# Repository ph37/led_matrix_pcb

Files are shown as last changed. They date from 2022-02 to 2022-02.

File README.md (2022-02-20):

# 32x16 LED Array PCB using 788BS

KiKad 5.1 files for the design of an LED matrix. The board has been manufactured by PCB Way and is
working.

The design is based around 788BS LED modules, which each contain 8x8 red LEDs in a common cathode
configuration.

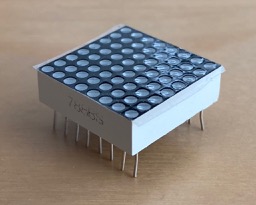
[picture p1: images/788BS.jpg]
Photo of 788BS


While physically a 16 row and 32 column design, it is logically organised as 8 rows and 64
columns. Logical row N drives physical rows N and N+8.

Uses a 3-pin header to drive a series of 74HC595 shift registers. First shift register is connected to a 
74HC238 3-to-8 decoder to provide hardware enforced one-hot enable of rows. Rows are driven by a PMV16XN 
SMT power MOSFET to provide enough current to drive 32 LED columns.

Another eight 8-bit shift registers provide control over the 64 columns, with each column
using a 680 ohm resistor to limit current. Brightness of individual LEDs can be supported
externally by reprogramming the shift register and pulse-width-modulating the on-time for
each column.

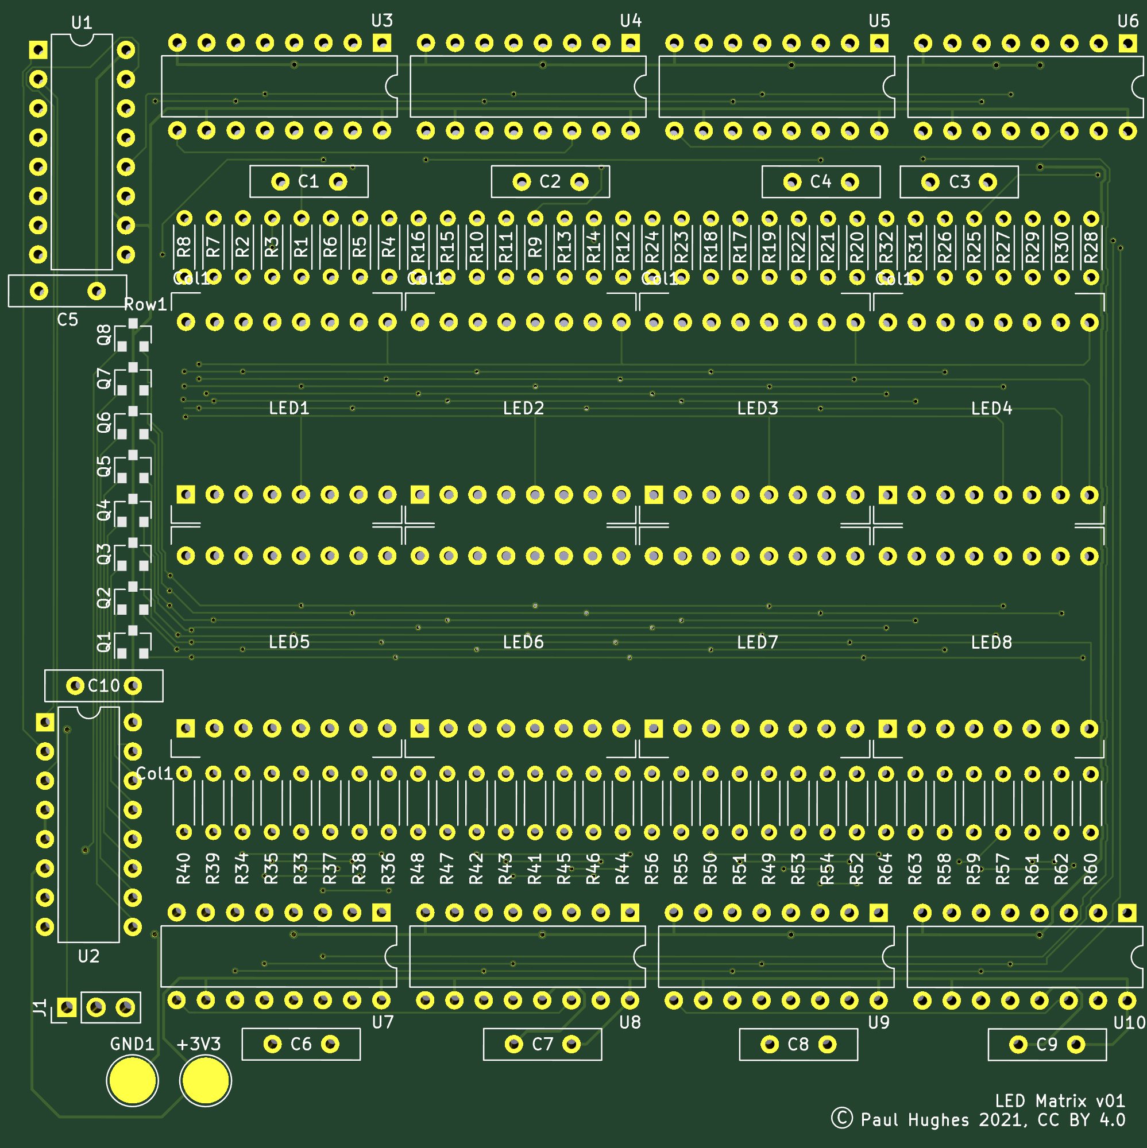
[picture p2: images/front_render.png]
Render of PCB


## Notes

Board layout is intended for manufacture by PCB Way and follows PCB Way design rules. Please check
compatibility with design rules for any other PCB house.

Board is a very basic design and intended for low frequency operation only. In particular there is
no ground plane, which I plan to include in a future revision.

Take care with 788BS parts, I recommend testing them before soldering onto the board. 
The first board I've built has a short circuit inside one of 788BS components, are these 
are difficult to remove as the pins are underneath the package.

## Errata

v01 of the board transposed rows 6 and 7 on the included 788BS symbol. This can be resolved
by transposing the data for these rows in software before driving the serial interface.

## Future

I plan to release C drivers for Paspberry Pi Pico. Eventually I plan to migrate the IO the Pico's
programmable IO.

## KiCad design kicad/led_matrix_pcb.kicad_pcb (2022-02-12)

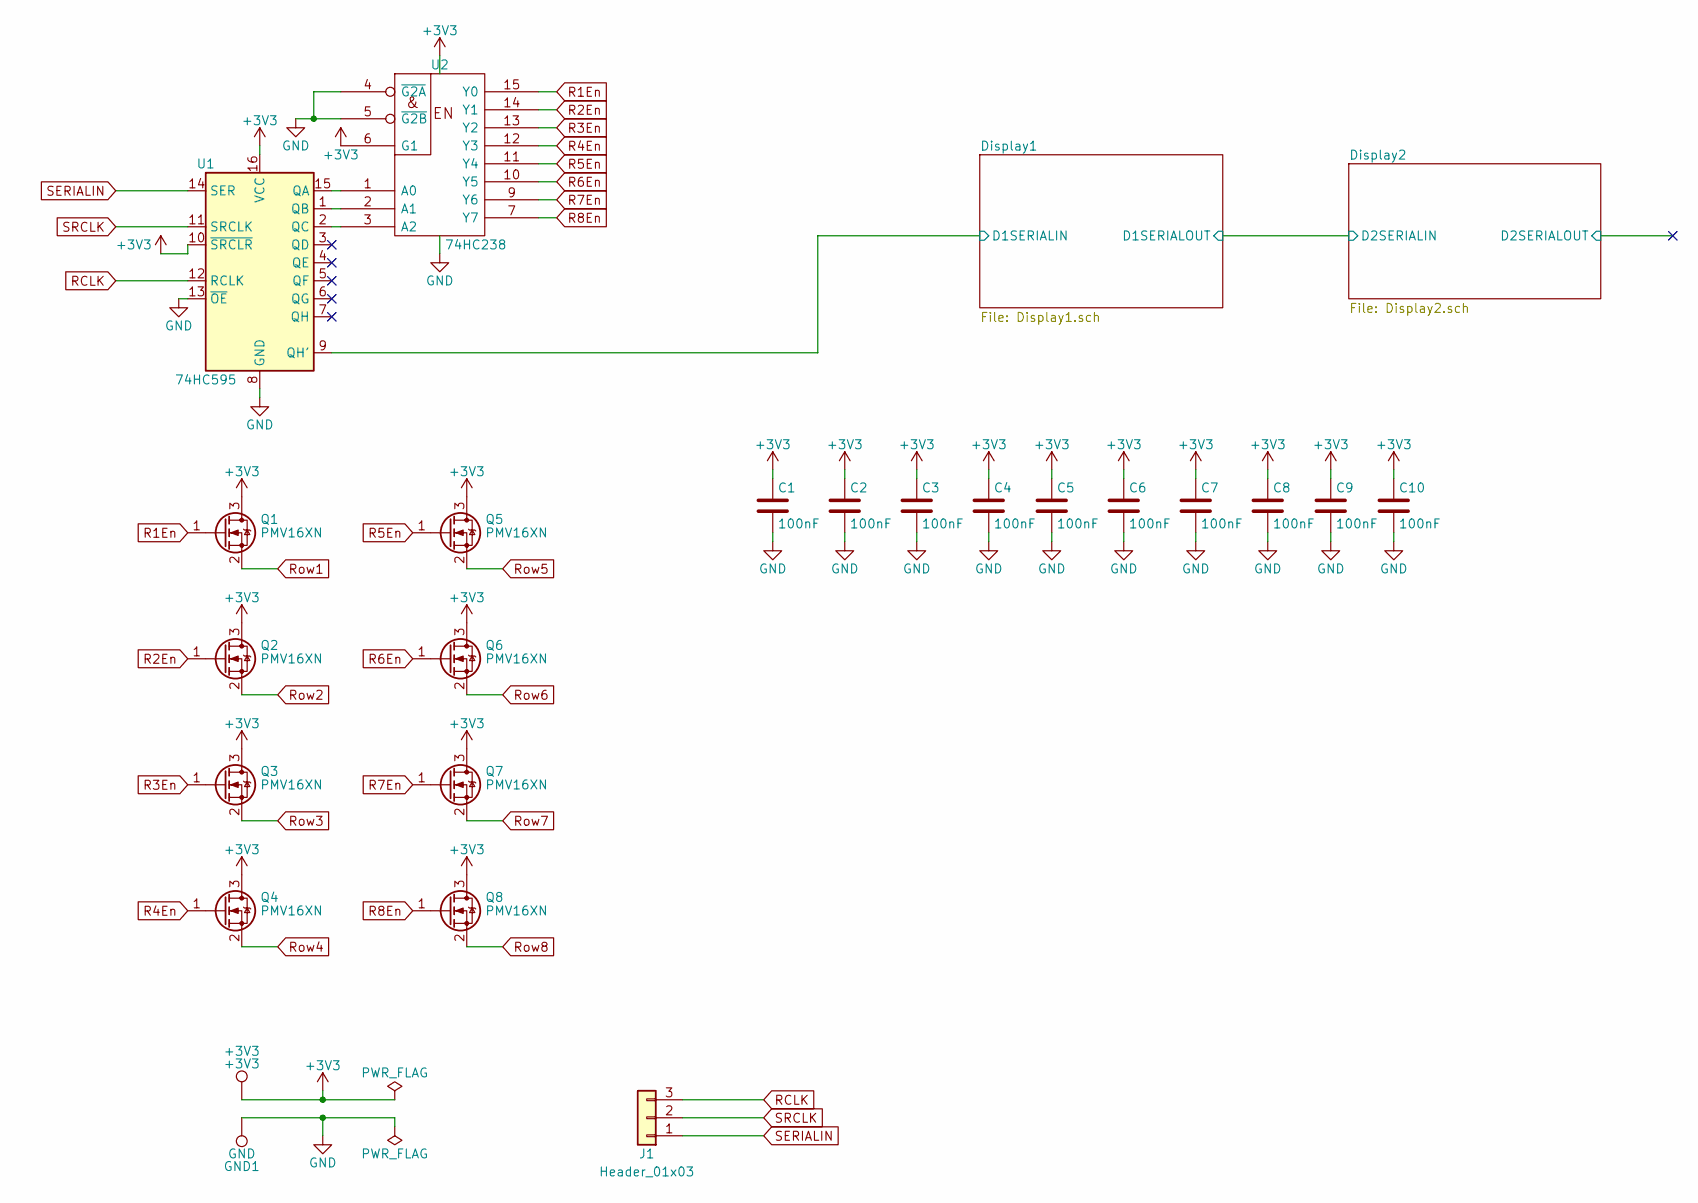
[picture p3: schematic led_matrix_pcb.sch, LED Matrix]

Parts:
+3V3: +3V3; TestPoint_Pad_D4.0mm
C1, C2, C3, C4, C5, C6, C7, C8, C9, C10: 100nF; C_Disc_D10.0mm_W2.5mm_P5.00mm
GND1: GND; TestPoint_Pad_D4.0mm
J1: Header_01x03; PinHeader_1x03_P2.54mm_Vertical
Q1, Q2, Q3, Q4, Q5, Q6, Q7, Q8: PMV16XN; SOT-23
U1: 74HC595; DIP-16_W7.62mm
U2: 74HC238; DIP-16_W7.62mm

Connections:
+3V3: +3V3.1, C1.1, C2.1, C3.1, C4.1, C5.1, C6.1, C7.1, C8.1, C9.1, C10.1, Q1.3 (D), Q2.3 (D), Q3.3 (D), Q4.3 (D), Q5.3 (D), Q6.3 (D), Q7.3 (D), Q8.3 (D), U1.10 (~SRCLR), U1.16 (VCC), U2.6 (G1), U2.16 (VCC); also elsewhere on the board
/Display1/D1SERIALIN: U1.9 (QH'); also elsewhere on the board
GND: C1.2, C2.2, C3.2, C4.2, C5.2, C6.2, C7.2, C8.2, C9.2, C10.2, GND1.1, U1.8 (GND), U1.13 (~OE), U2.4 (~G2A), U2.5 (~G2B), U2.8 (GND); also elsewhere on the board
unnamed: U1.1 (QB), U2.2 (A1)
unnamed: U1.2 (QC), U2.3 (A2)
unnamed: U1.15 (QA), U2.1 (A0)
R1En: Q1.1 (G), U2.15 (Y0)
R2En: Q2.1 (G), U2.14 (Y1)
R3En: Q3.1 (G), U2.13 (Y2)
R4En: Q4.1 (G), U2.12 (Y3)
R5En: Q5.1 (G), U2.11 (Y4)
R6En: Q6.1 (G), U2.10 (Y5)
R7En: Q7.1 (G), U2.9 (Y6)
R8En: Q8.1 (G), U2.7 (Y7)
RCLK: J1.3, U1.12 (RCLK); also elsewhere on the board
Row1: Q1.2 (S); also elsewhere on the board
Row2: Q2.2 (S); also elsewhere on the board
Row3: Q3.2 (S); also elsewhere on the board
Row4: Q4.2 (S); also elsewhere on the board
Row5: Q5.2 (S); also elsewhere on the board
Row6: Q6.2 (S); also elsewhere on the board
Row7: Q7.2 (S); also elsewhere on the board
Row8: Q8.2 (S); also elsewhere on the board
SERIALIN: J1.1, U1.14 (SER)
SRCLK: J1.2, U1.11 (SRCLK); also elsewhere on the board

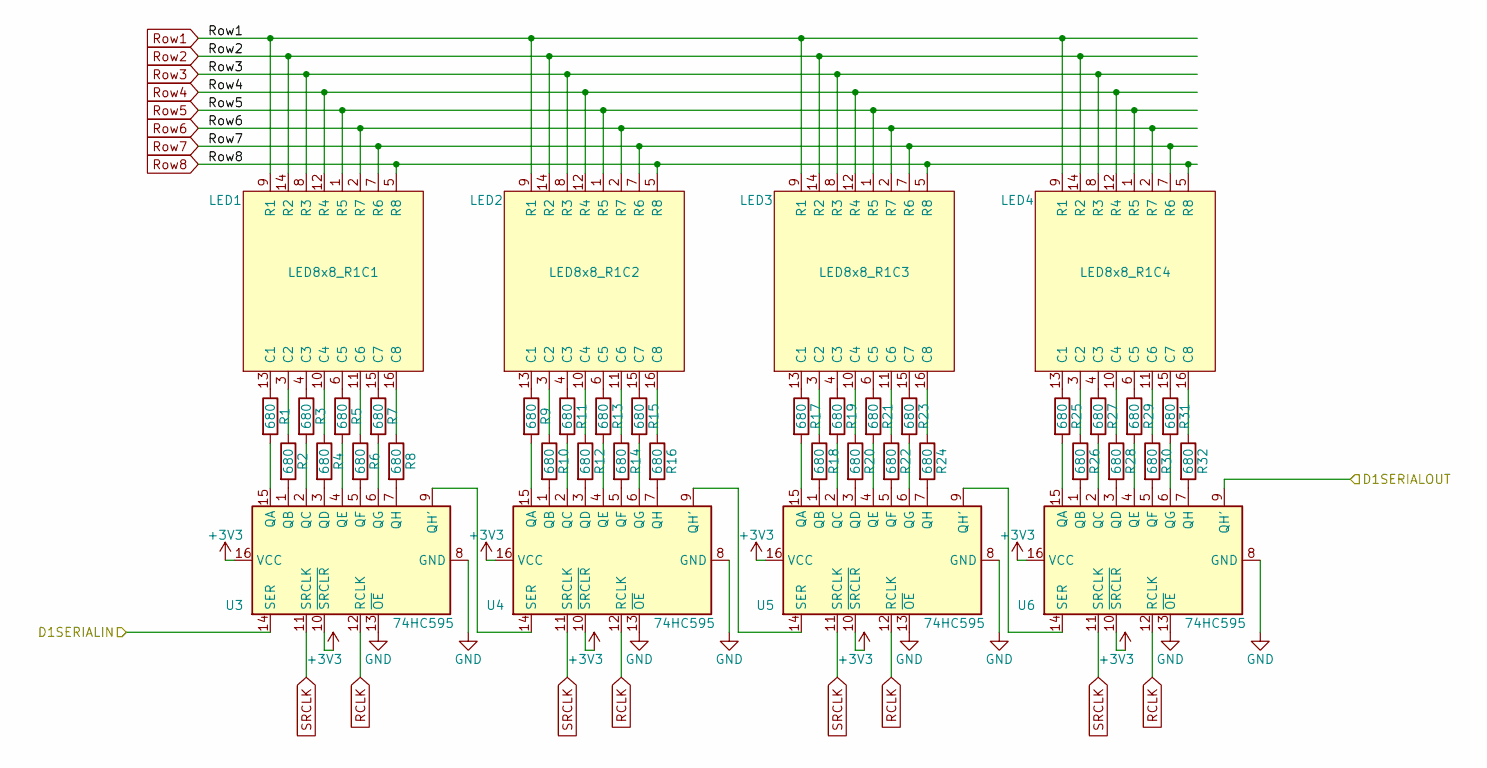
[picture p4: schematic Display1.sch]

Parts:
LED1: LED8x8_R1C1; 788BS
LED2: LED8x8_R1C2; 788BS
LED3: LED8x8_R1C3; 788BS
LED4: LED8x8_R1C4; 788BS
R1, R2, R3, R4, R5, R6, R7, R8, R9, R10, R11, R12, R13, R14, R15, R16, R17, R18, R19, R20, R21, R22, R23, R24, R25, R26, R27, R28, R29, R30, R31, R32: 680; R_Axial_DIN0204_L3.6mm_D1.6mm_P5.08mm_Horizontal
U3, U4, U5, U6: 74HC595; DIP-16_W7.62mm

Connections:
+3V3: U3.10 (~SRCLR), U3.16 (VCC), U4.10 (~SRCLR), U4.16 (VCC), U5.10 (~SRCLR), U5.16 (VCC), U6.10 (~SRCLR), U6.16 (VCC); also elsewhere on the board
/Display1/D1SERIALIN: U3.14 (SER); also elsewhere on the board
/Display1/D1SERIALOUT: U6.9 (QH'); also elsewhere on the board
GND: U3.8 (GND), U3.13 (~OE), U4.8 (GND), U4.13 (~OE), U5.8 (GND), U5.13 (~OE), U6.8 (GND), U6.13 (~OE); also elsewhere on the board
unnamed: LED1.3 (C2), R2.1
unnamed: LED1.4 (C3), R3.1
unnamed: LED1.6 (C5), R5.1
unnamed: LED1.10 (C4), R4.1
unnamed: LED1.11 (C6), R6.1
unnamed: LED1.13 (C1), R1.1
unnamed: LED1.15 (C7), R7.1
unnamed: LED1.16 (C8), R8.1
unnamed: LED2.3 (C2), R10.1
unnamed: LED2.4 (C3), R11.1
unnamed: LED2.6 (C5), R13.1
unnamed: LED2.10 (C4), R12.1
unnamed: LED2.11 (C6), R14.1
unnamed: LED2.13 (C1), R9.1
unnamed: LED2.15 (C7), R15.1
unnamed: LED2.16 (C8), R16.1
unnamed: LED3.3 (C2), R18.1
unnamed: LED3.4 (C3), R19.1
unnamed: LED3.6 (C5), R21.1
unnamed: LED3.10 (C4), R20.1
unnamed: LED3.11 (C6), R22.1
unnamed: LED3.13 (C1), R17.1
unnamed: LED3.15 (C7), R23.1
unnamed: LED3.16 (C8), R24.1
unnamed: LED4.3 (C2), R26.1
unnamed: LED4.4 (C3), R27.1
unnamed: LED4.6 (C5), R29.1
unnamed: LED4.10 (C4), R28.1
unnamed: LED4.11 (C6), R30.1
unnamed: LED4.13 (C1), R25.1
unnamed: LED4.15 (C7), R31.1
unnamed: LED4.16 (C8), R32.1
unnamed: R1.2, U3.15 (QA)
unnamed: R2.2, U3.1 (QB)
unnamed: R3.2, U3.2 (QC)
unnamed: R4.2, U3.3 (QD)
unnamed: R5.2, U3.4 (QE)
unnamed: R6.2, U3.5 (QF)
unnamed: R7.2, U3.6 (QG)
unnamed: R8.2, U3.7 (QH)
unnamed: R9.2, U4.15 (QA)
unnamed: R10.2, U4.1 (QB)
unnamed: R11.2, U4.2 (QC)
unnamed: R12.2, U4.3 (QD)
unnamed: R13.2, U4.4 (QE)
unnamed: R14.2, U4.5 (QF)
unnamed: R15.2, U4.6 (QG)
unnamed: R16.2, U4.7 (QH)
unnamed: R17.2, U5.15 (QA)
unnamed: R18.2, U5.1 (QB)
unnamed: R19.2, U5.2 (QC)
unnamed: R20.2, U5.3 (QD)
unnamed: R21.2, U5.4 (QE)
unnamed: R22.2, U5.5 (QF)
unnamed: R23.2, U5.6 (QG)
unnamed: R24.2, U5.7 (QH)
unnamed: R25.2, U6.15 (QA)
unnamed: R26.2, U6.1 (QB)
unnamed: R27.2, U6.2 (QC)
unnamed: R28.2, U6.3 (QD)
unnamed: R29.2, U6.4 (QE)
unnamed: R30.2, U6.5 (QF)
unnamed: R31.2, U6.6 (QG)
unnamed: R32.2, U6.7 (QH)
unnamed: U3.9 (QH'), U4.14 (SER)
unnamed: U4.9 (QH'), U5.14 (SER)
unnamed: U5.9 (QH'), U6.14 (SER)
RCLK: U3.12 (RCLK), U4.12 (RCLK), U5.12 (RCLK), U6.12 (RCLK); also elsewhere on the board
Row1: LED1.9 (R1), LED2.9 (R1), LED3.9 (R1), LED4.9 (R1); also elsewhere on the board
Row2: LED1.14 (R2), LED2.14 (R2), LED3.14 (R2), LED4.14 (R2); also elsewhere on the board
Row3: LED1.8 (R3), LED2.8 (R3), LED3.8 (R3), LED4.8 (R3); also elsewhere on the board
Row4: LED1.12 (R4), LED2.12 (R4), LED3.12 (R4), LED4.12 (R4); also elsewhere on the board
Row5: LED1.1 (R5), LED2.1 (R5), LED3.1 (R5), LED4.1 (R5); also elsewhere on the board
Row6: LED1.2 (R7), LED2.2 (R7), LED3.2 (R7), LED4.2 (R7); also elsewhere on the board
Row7: LED1.7 (R6), LED2.7 (R6), LED3.7 (R6), LED4.7 (R6); also elsewhere on the board
Row8: LED1.5 (R8), LED2.5 (R8), LED3.5 (R8), LED4.5 (R8); also elsewhere on the board
SRCLK: U3.11 (SRCLK), U4.11 (SRCLK), U5.11 (SRCLK), U6.11 (SRCLK); also elsewhere on the board

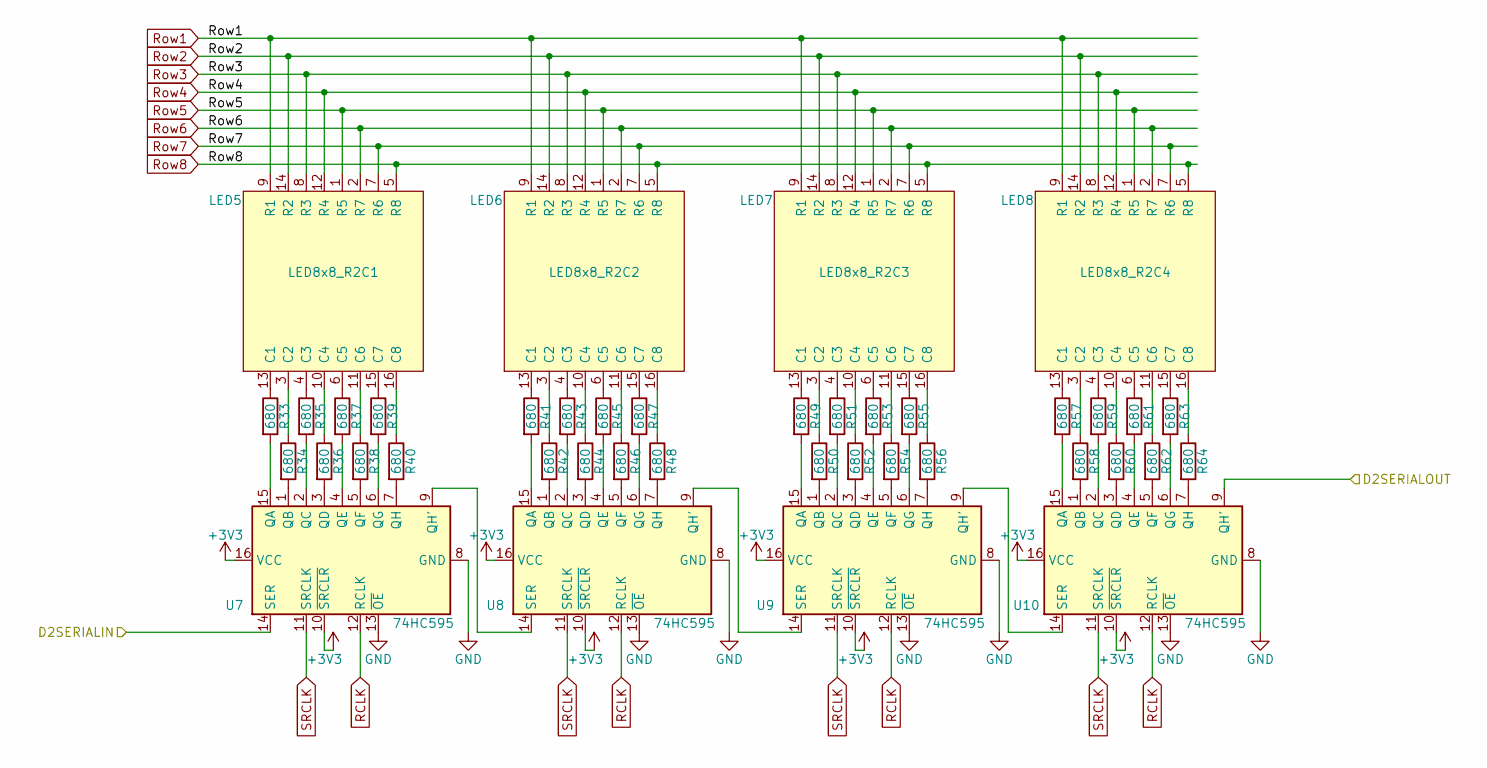
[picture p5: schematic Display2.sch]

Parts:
LED5: LED8x8_R2C1; 788BS
LED6: LED8x8_R2C2; 788BS
LED7: LED8x8_R2C3; 788BS
LED8: LED8x8_R2C4; 788BS
R33, R34, R35, R36, R37, R38, R39, R40, R41, R42, R43, R44, R45, R46, R47, R48, R49, R50, R51, R52, R53, R54, R55, R56, R57, R58, R59, R60, R61, R62, R63, R64: 680; R_Axial_DIN0204_L3.6mm_D1.6mm_P5.08mm_Horizontal
U7, U8, U9, U10: 74HC595; DIP-16_W7.62mm

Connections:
+3V3: U7.10 (~SRCLR), U7.16 (VCC), U8.10 (~SRCLR), U8.16 (VCC), U9.10 (~SRCLR), U9.16 (VCC), U10.10 (~SRCLR), U10.16 (VCC); also elsewhere on the board
/Display1/D1SERIALOUT: U7.14 (SER); also elsewhere on the board
/Display2/D2SERIALOUT: U10.9 (QH')
GND: U7.8 (GND), U7.13 (~OE), U8.8 (GND), U8.13 (~OE), U9.8 (GND), U9.13 (~OE), U10.8 (GND), U10.13 (~OE); also elsewhere on the board
unnamed: LED5.3 (C2), R34.1
unnamed: LED5.4 (C3), R35.1
unnamed: LED5.6 (C5), R37.1
unnamed: LED5.10 (C4), R36.1
unnamed: LED5.11 (C6), R38.1
unnamed: LED5.13 (C1), R33.1
unnamed: LED5.15 (C7), R39.1
unnamed: LED5.16 (C8), R40.1
unnamed: LED6.3 (C2), R42.1
unnamed: LED6.4 (C3), R43.1
unnamed: LED6.6 (C5), R45.1
unnamed: LED6.10 (C4), R44.1
unnamed: LED6.11 (C6), R46.1
unnamed: LED6.13 (C1), R41.1
unnamed: LED6.15 (C7), R47.1
unnamed: LED6.16 (C8), R48.1
unnamed: LED7.3 (C2), R50.1
unnamed: LED7.4 (C3), R51.1
unnamed: LED7.6 (C5), R53.1
unnamed: LED7.10 (C4), R52.1
unnamed: LED7.11 (C6), R54.1
unnamed: LED7.13 (C1), R49.1
unnamed: LED7.15 (C7), R55.1
unnamed: LED7.16 (C8), R56.1
unnamed: LED8.3 (C2), R58.1
unnamed: LED8.4 (C3), R59.1
unnamed: LED8.6 (C5), R61.1
unnamed: LED8.10 (C4), R60.1
unnamed: LED8.11 (C6), R62.1
unnamed: LED8.13 (C1), R57.1
unnamed: LED8.15 (C7), R63.1
unnamed: LED8.16 (C8), R64.1
unnamed: R33.2, U7.15 (QA)
unnamed: R34.2, U7.1 (QB)
unnamed: R35.2, U7.2 (QC)
unnamed: R36.2, U7.3 (QD)
unnamed: R37.2, U7.4 (QE)
unnamed: R38.2, U7.5 (QF)
unnamed: R39.2, U7.6 (QG)
unnamed: R40.2, U7.7 (QH)
unnamed: R41.2, U8.15 (QA)
unnamed: R42.2, U8.1 (QB)
unnamed: R43.2, U8.2 (QC)
unnamed: R44.2, U8.3 (QD)
unnamed: R45.2, U8.4 (QE)
unnamed: R46.2, U8.5 (QF)
unnamed: R47.2, U8.6 (QG)
unnamed: R48.2, U8.7 (QH)
unnamed: R49.2, U9.15 (QA)
unnamed: R50.2, U9.1 (QB)
unnamed: R51.2, U9.2 (QC)
unnamed: R52.2, U9.3 (QD)
unnamed: R53.2, U9.4 (QE)
unnamed: R54.2, U9.5 (QF)
unnamed: R55.2, U9.6 (QG)
unnamed: R56.2, U9.7 (QH)
unnamed: R57.2, U10.15 (QA)
unnamed: R58.2, U10.1 (QB)
unnamed: R59.2, U10.2 (QC)
unnamed: R60.2, U10.3 (QD)
unnamed: R61.2, U10.4 (QE)
unnamed: R62.2, U10.5 (QF)
unnamed: R63.2, U10.6 (QG)
unnamed: R64.2, U10.7 (QH)
unnamed: U7.9 (QH'), U8.14 (SER)
unnamed: U8.9 (QH'), U9.14 (SER)
unnamed: U9.9 (QH'), U10.14 (SER)
RCLK: U7.12 (RCLK), U8.12 (RCLK), U9.12 (RCLK), U10.12 (RCLK); also elsewhere on the board
Row1: LED5.9 (R1), LED6.9 (R1), LED7.9 (R1), LED8.9 (R1); also elsewhere on the board
Row2: LED5.14 (R2), LED6.14 (R2), LED7.14 (R2), LED8.14 (R2); also elsewhere on the board
Row3: LED5.8 (R3), LED6.8 (R3), LED7.8 (R3), LED8.8 (R3); also elsewhere on the board
Row4: LED5.12 (R4), LED6.12 (R4), LED7.12 (R4), LED8.12 (R4); also elsewhere on the board
Row5: LED5.1 (R5), LED6.1 (R5), LED7.1 (R5), LED8.1 (R5); also elsewhere on the board
Row6: LED5.2 (R7), LED6.2 (R7), LED7.2 (R7), LED8.2 (R7); also elsewhere on the board
Row7: LED5.7 (R6), LED6.7 (R6), LED7.7 (R6), LED8.7 (R6); also elsewhere on the board
Row8: LED5.5 (R8), LED6.5 (R8), LED7.5 (R8), LED8.5 (R8); also elsewhere on the board
SRCLK: U7.11 (SRCLK), U8.11 (SRCLK), U9.11 (SRCLK), U10.11 (SRCLK); also elsewhere on the board

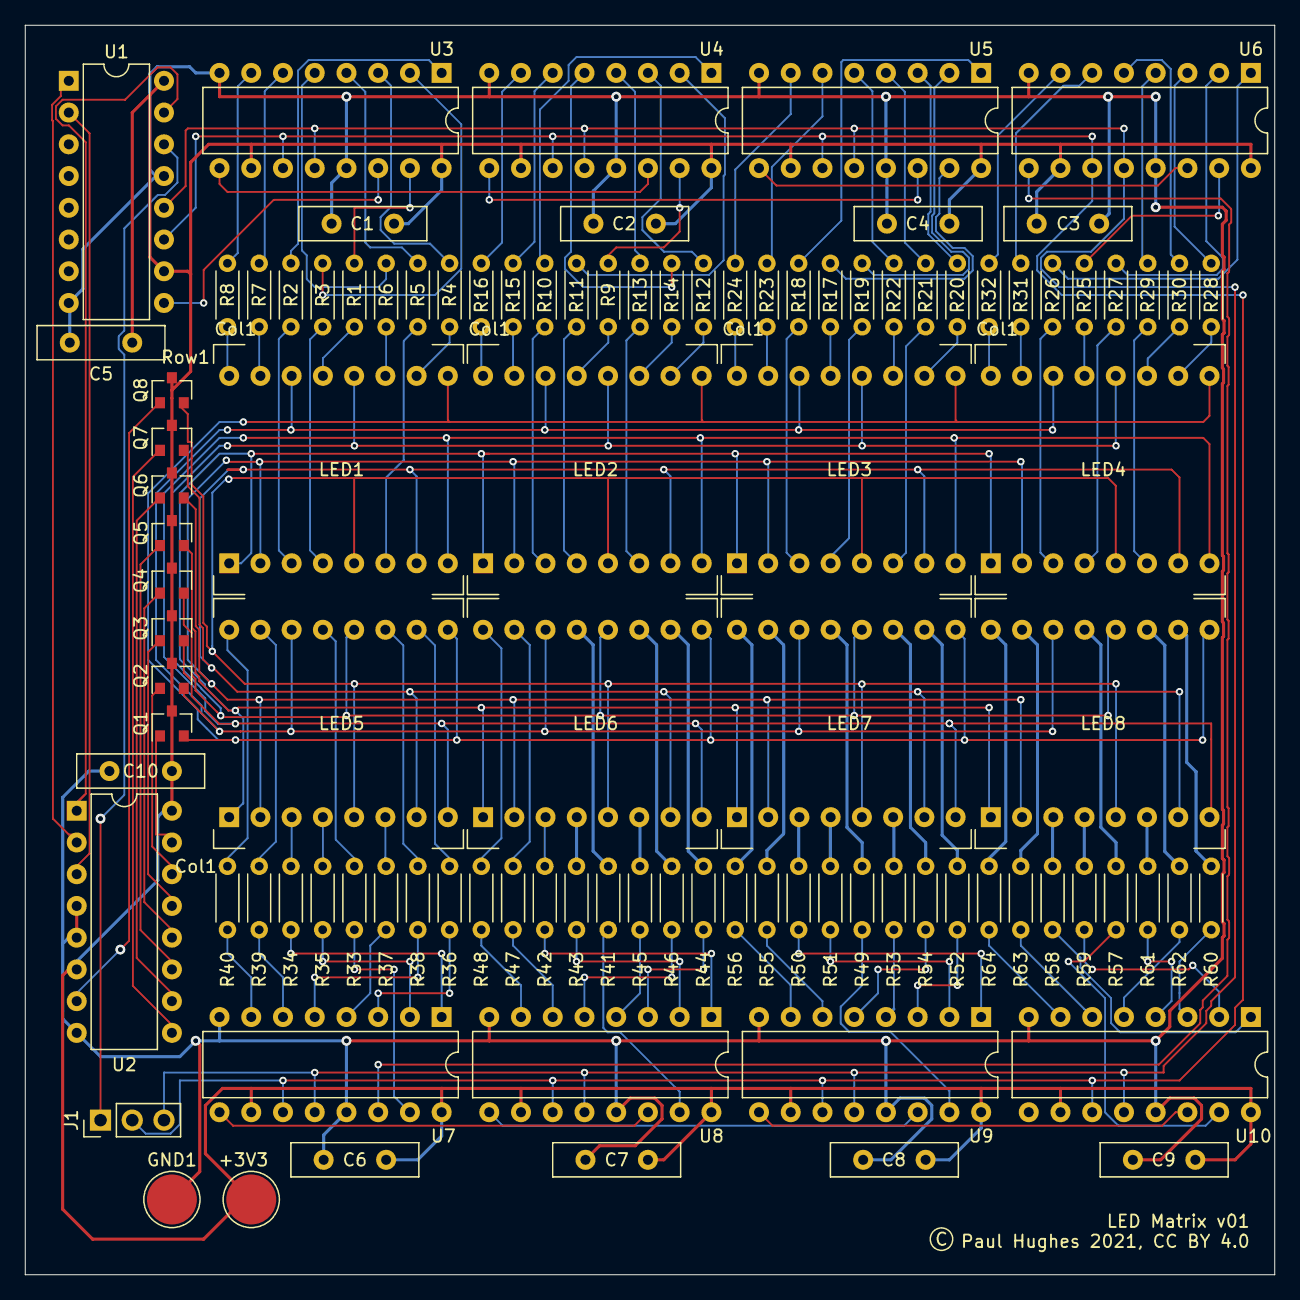
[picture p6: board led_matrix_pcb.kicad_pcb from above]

Board: 2 copper layers, 100.0 x 100.0 mm, 103 parts (0 on the bottom side), 160 nets.

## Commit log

2022-02-12 Initial commit of led_matrix_pcb
    Initial commit of files with modifications to support
    open source release. Includes necessary libraries.
    [Display1.sch, Display2.sch, led_matrix_pcb.kicad_pcb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]
2022-02-12 Fix library name in LED8x8 instances in schematic
    [Display1.sch, Display2.sch]
2022-02-12 Added rendering of PCB for README
2022-02-12 Added supported KiCad version
2022-02-12 Added info on 788BS
    [Display1.sch, Display2.sch, led_matrix_pcb.kicad_pcb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]

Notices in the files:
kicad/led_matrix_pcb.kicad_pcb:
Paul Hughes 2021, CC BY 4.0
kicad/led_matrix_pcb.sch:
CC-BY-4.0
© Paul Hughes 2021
